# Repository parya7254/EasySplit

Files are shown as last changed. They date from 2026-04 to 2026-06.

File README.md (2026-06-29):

# EasySplit
A hot-swappable split keyboard with a traditional Layout! It will feature MX Switches, a nice!nano (clone) as the main MCU for both sides, and a battery so that it can be used on the go!

WhatsApp Image 2026-06-29 at 4 52 29 PM



# Why Did I Make This??
In school, I type A LOT. And typing on a school chromebook, is well, okay I guess, and I want to have a better typing experience when I type things, and well, I like making my own things and finding my own solutions. So I made this split keyboard. It's wireless, battery-powered, and best of all, **made by ME**. This keyboard will help me type my essays faster, work more efficiently, and also turn in my assignments **ON TIME**. *Ahhh*, yes, that's the feeling of making your own solutions and being proud of it.

# How Was it Made??

The PCB was designed using KiCAD and the case for it was designed in Fusion360. The pictures of the schematic and the PCB are below: 

This is the schematic which was designed in KiCad:





And this is the actual PCB which was also designed in KiCad:



# BOM
These will be the parts that I will use to build and assemble my split keyboard along with the links to get them:

| Name | Purpose | Quantity | Total Cost (USD) | Link | Distributor |
|---|---|---|---|---|---|
| PCB Mount Stabilizers Set | These will prevent wobble when pressing longer keys from the sides! | 1 | 9.99 | https://www.amazon.com/GLORIOUS-Stabilizer-Mechanical-Keyboards-Compatible/dp/B09MZKFLXP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 | Amazon |
| MX Hotswap Sockets (110pcs) | These will be the hotswap sockets for my split keyboard! They will allow for the switches to be removable and replaceable. | 1 | 7.99 | https://www.aliexpress.us/item/3256807045726008.html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 | AliExpress |
| 2.0mm JST Connector 2 Pin (5 Pairs) | This will be used to connect the battery to the nice!nano and using this, the battery can also be quickly removed without needing to be desoldered in case of problems or to power off the keyboard. | 1 | 1.76 | https://www.aliexpress.us/item/3256802377876396.html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 | AliExpress |
| nice!nano Clone | This will be the main MCU for both sides of my keyboard! It will basically read the key presses and send the respective key commands to the connected device. And it also has Bluetooth and a charging IC which means that the two halves of my split keyboard would be wirelessly connected and I can also directly charge my battery from it. | 2 | 5.52 | https://www.aliexpress.us/item/3256807196955871.html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 | AliExpress |
| 1N4148W SMD Small Signal Fast Switching Diodes (100pcs) | These will be the diodes that will be used in my switch matrix that will also help the microcontroller to read the pressed switches properly! | 1 | 1.38 | https://www.aliexpress.us/item/3256805388348871.html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 | AliExpress |
| ELUTENG Ice Blue Mechanical Keyboard Switches (100pcs) | These will be the switches that will be used in my keyboard! | 1 | 15.99 | https://www.amazon.com/gp/product/B0DHCLLH33/ref=ewc_pr_img_1?smid=A3GES9IA7UE877&th=1 | Amazon |
| 3.7V Battery (2pcs) | This will be the battery that will power both halves of my keyboard! | 1 | 8.35 | https://www.aliexpress.us/item/3256811793052939.html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 | AliExpress |
| Keycap Set | These will be the keycaps that I will use for my keyboard! | 1 | 14.39 | https://www.amazon.com/gp/product/B0BK3HK7SR/ref=ox_sc_act_image_1?smid=A157804XWFVRE0&th=1 | Amazon |
| PCB (Left and Right) MOQ: 5 | This will be my split keyboard's circuit board! | 5 | 34.00 | https://jlcpcb.com/ | JLCPCB |

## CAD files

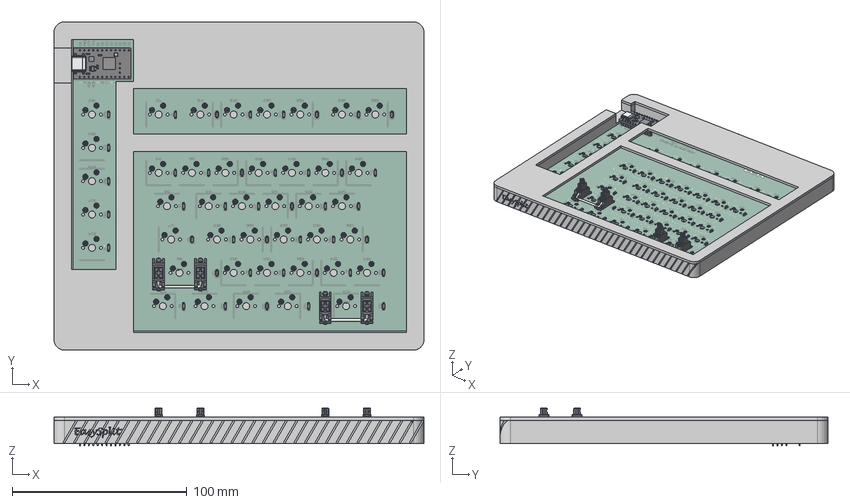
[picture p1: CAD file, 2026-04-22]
CAD/Left/EasySplit-Left-Assembled.stp
211.5 x 187.7 x 21.5 mm
D_SOD-123 x 42
Hotswap_MX x 42
PinHeader_1x12_P2.54mm_Vertical.step
User Library-TYPE-C-31-M-14.step
MICRO_603 resistor 102
micro_crystal 5x3
MICRO_led
micro_MIC5219
Stabilizer_MX_2.00u x 2
EasySplit - Left_copper
EasySplit - Left_pad
EasySplit - Left_via
EasySplit - Left_silkscreen
EasySplit - Left_silkscreen_1
EasySplit - Left_soldermask
EasySplit - Left_soldermask_1
EasySplit - Left_PCB

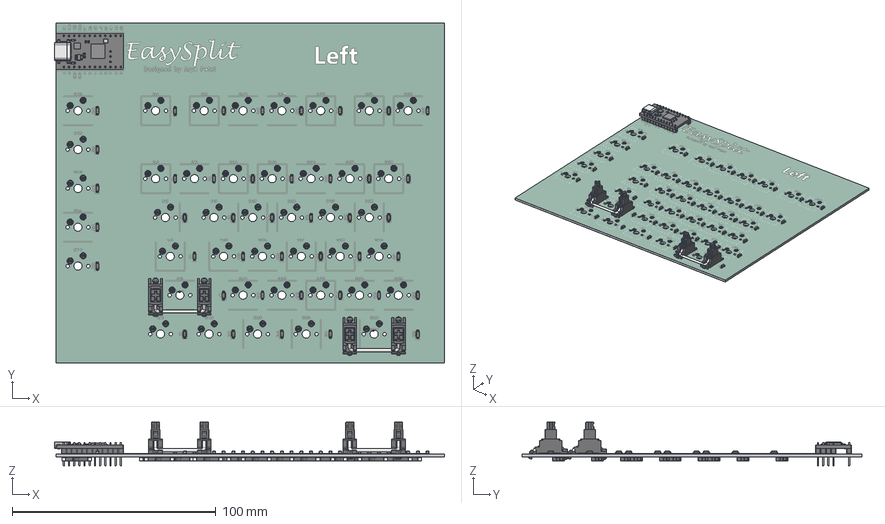
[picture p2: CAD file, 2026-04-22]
CAD/Left/EasySplit+-+Left.stp
191.3 x 166.7 x 21.5 mm
D_SOD-123 x 42
Hotswap_MX x 42
PinHeader_1x12_P2.54mm_Vertical.step
User Library-TYPE-C-31-M-14.step
MICRO_603 resistor 102
micro_crystal 5x3
MICRO_led
micro_MIC5219
Stabilizer_MX_2.00u x 2
EasySplit - Left_copper
EasySplit - Left_pad
EasySplit - Left_via
EasySplit - Left_silkscreen
EasySplit - Left_silkscreen_1
EasySplit - Left_soldermask
EasySplit - Left_soldermask_1
EasySplit - Left_PCB

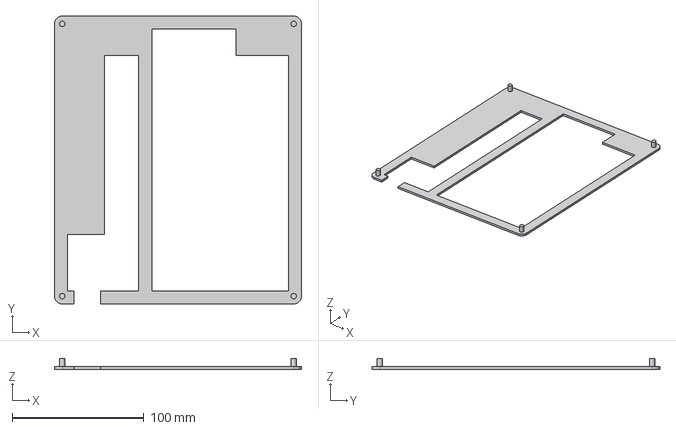
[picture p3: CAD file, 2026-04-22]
CAD/Right/EasySplit-Right-Top.stp
187.7 x 218.6 x 8.00 mm

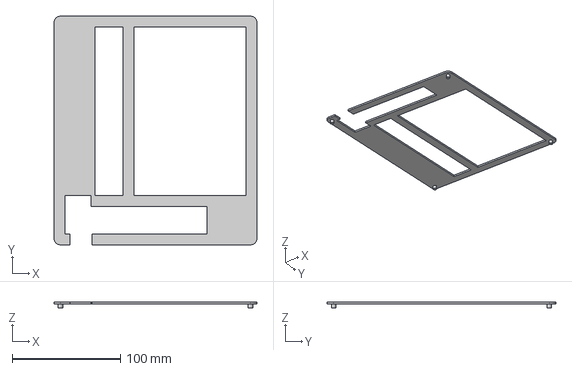
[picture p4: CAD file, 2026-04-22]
CAD/Left/EasySplit-Left-Top.stp
187.7 x 211.5 x 6.00 mm

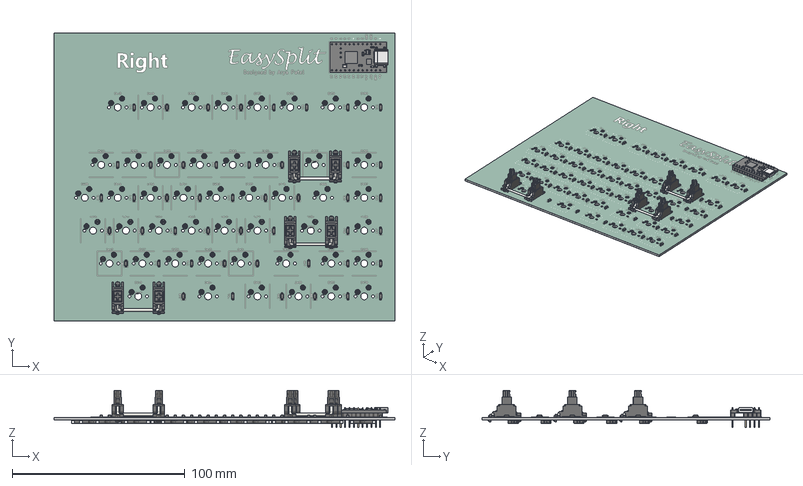
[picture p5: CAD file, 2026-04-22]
CAD/Right/EasySplit+-+Right.stp
197.6 x 166.7 x 21.5 mm
Hotswap_MX x 47
D_SOD-123 x 47
Stabilizer_MX_2.00u x 3
PinHeader_1x12_P2.54mm_Vertical.step
User Library-TYPE-C-31-M-14.step
MICRO_603 resistor 102
micro_crystal 5x3
MICRO_led
micro_MIC5219
EasySplit - Right_copper
EasySplit - Right_pad
EasySplit - Right_via
EasySplit - Right_silkscreen
EasySplit - Right_silkscreen_1
EasySplit - Right_soldermask
EasySplit - Right_soldermask_1
EasySplit - Right_PCB

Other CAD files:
CAD/EasySplit-Assembled-Full.f3z
CAD/Left/EasySplit+-+Left.f3d
CAD/Left/EasySplit-Left-Assembled.f3z
CAD/Left/EasySplit-Left-Top.f3d
CAD/Left/EasySplit-Left.f3d
CAD/Right/EasySplit+-+Right.f3d
CAD/Right/EasySplit-Right-Assembled.f3z
CAD/Right/EasySplit-Right-Top.f3d
CAD/Right/EasySplit-Right.f3d
CAD/Right/EasySplit-Right.stp

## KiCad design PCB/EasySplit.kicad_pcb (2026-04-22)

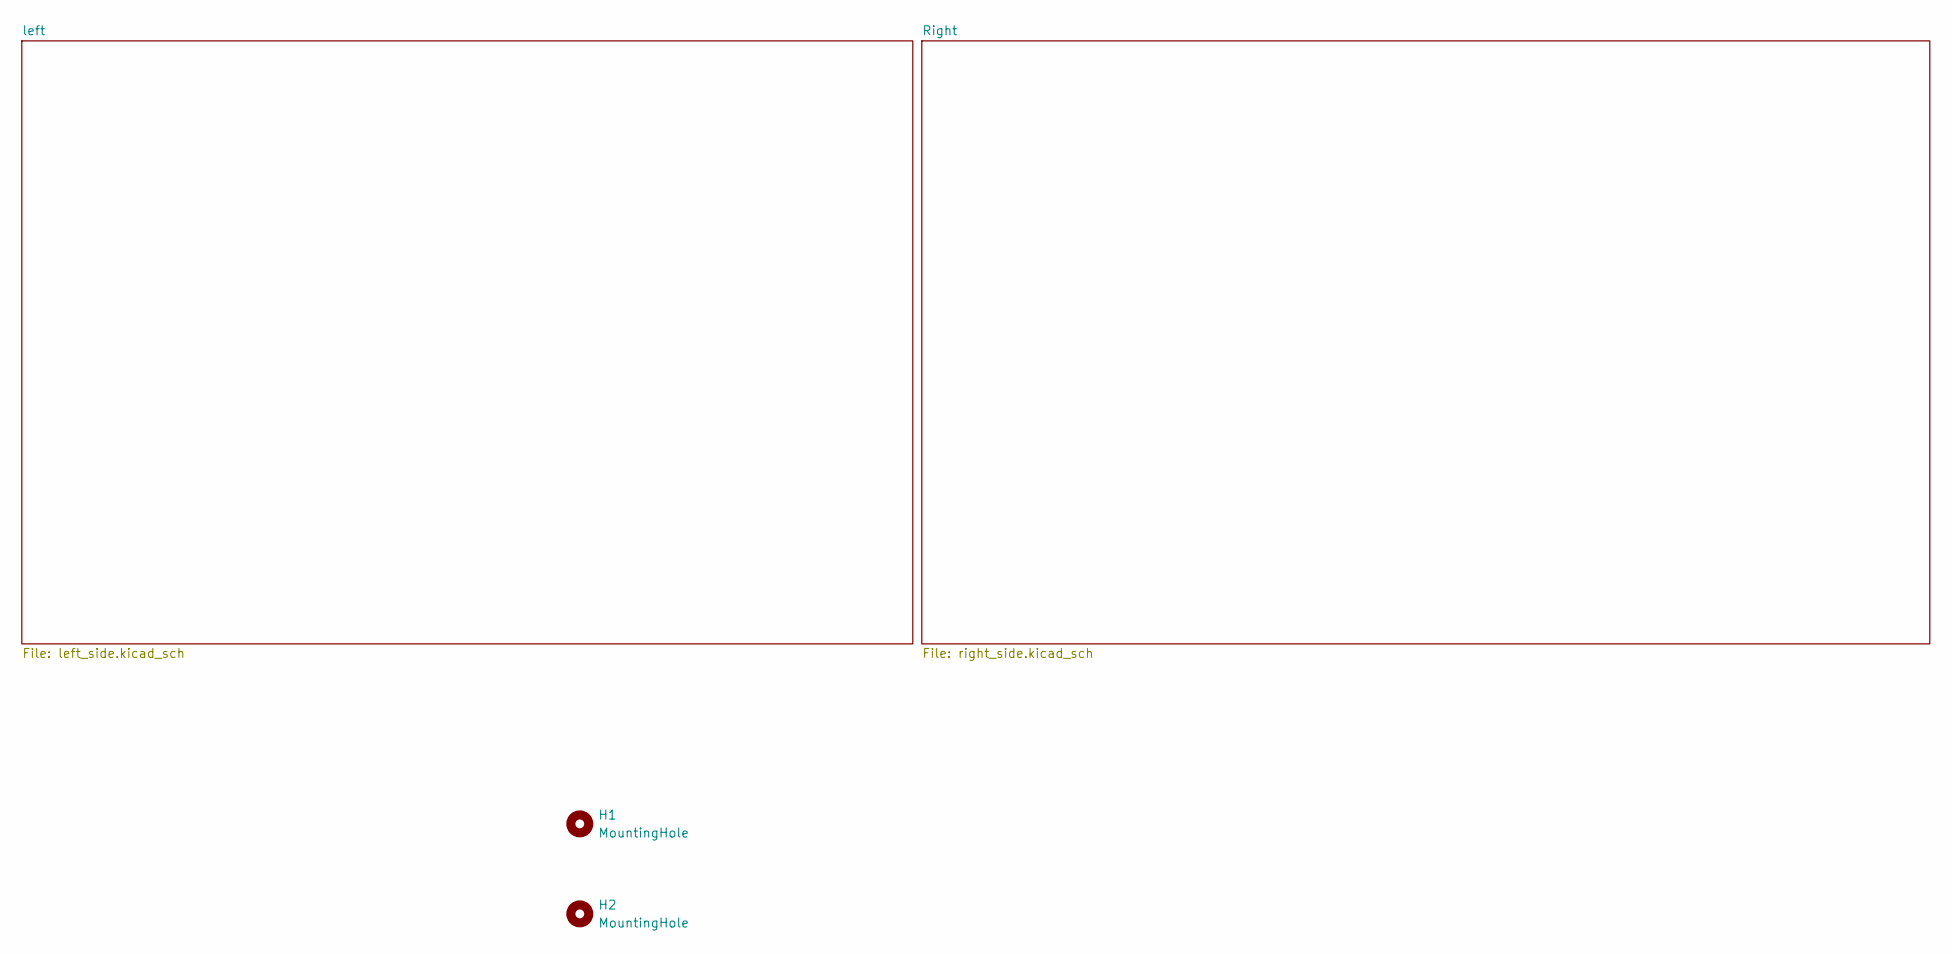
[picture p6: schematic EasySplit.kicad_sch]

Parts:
H1, H2: MountingHole; mouse-bite-5mm-slot

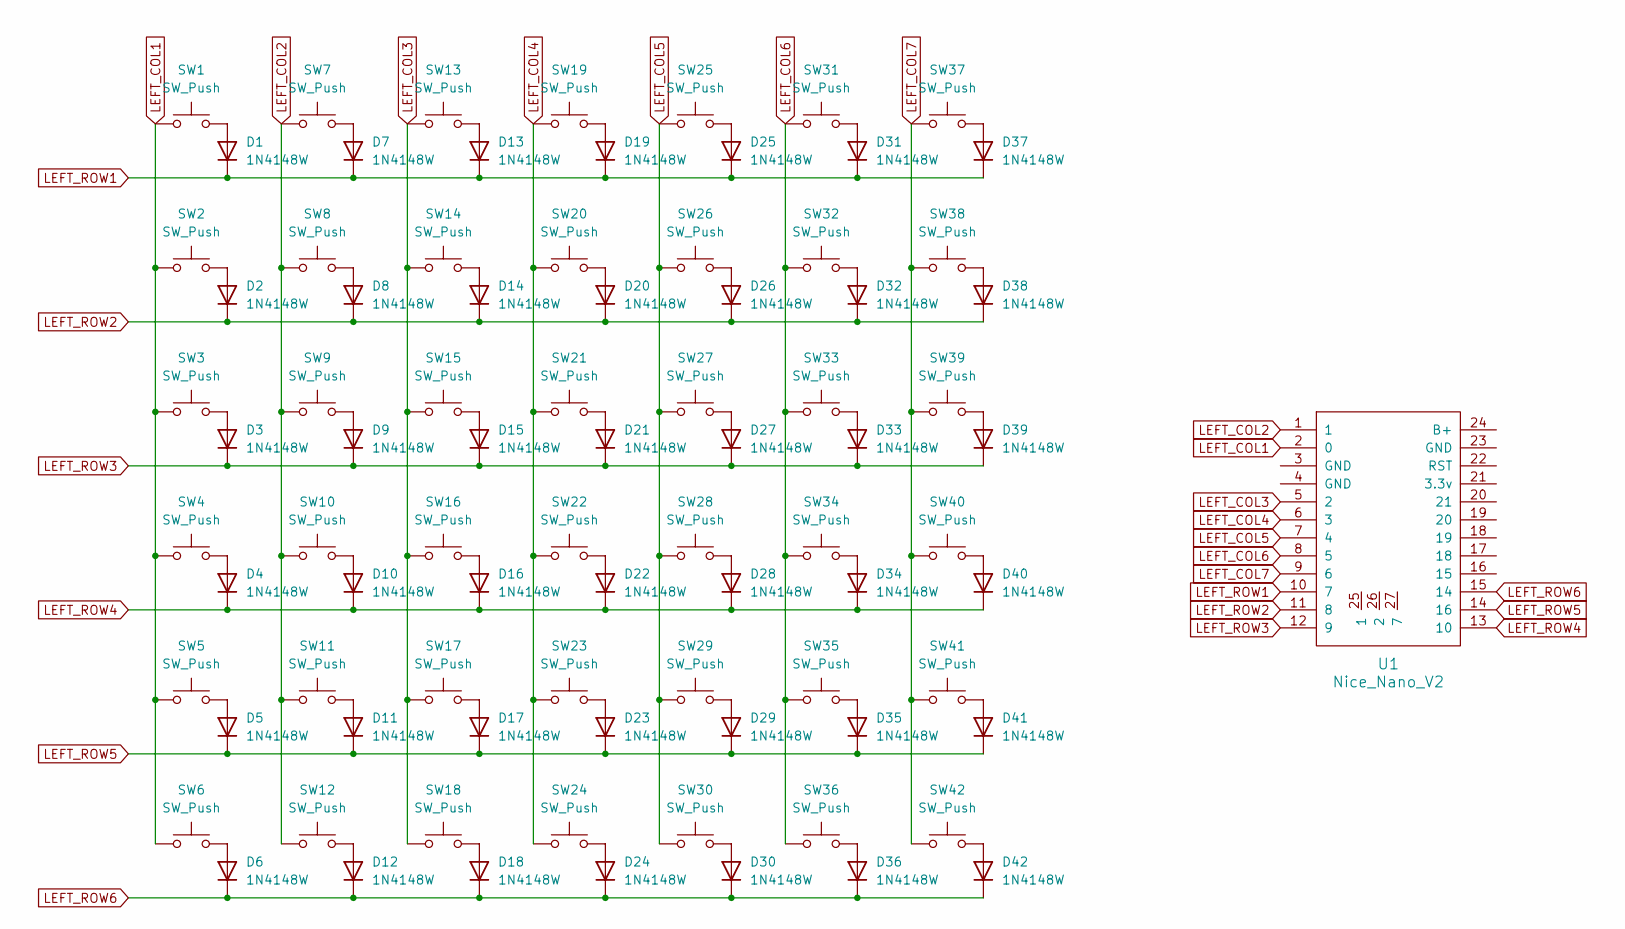
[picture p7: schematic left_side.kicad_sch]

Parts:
D1, D2, D3, D4, D5, D6, D7, D8, D9, D10, D11, D12, D13, D14, D15, D16, D17, D18, D19, D20, D21, D22, D23, D24, D25, D26, D27, D28, D29, D30, D31, D32, D33, D34, D35, D36, D37, D38, D39, D40, D41, D42: 1N4148W; D_SOD-123
SW1, SW2, SW7, SW8, SW9, SW10, SW11, SW13, SW14, SW15, SW16, SW17, SW19, SW20, SW21, SW22, SW23, SW25, SW26, SW27, SW28, SW29, SW31, SW32, SW33, SW34, SW35, SW36, SW37, SW38, SW39, SW40, SW41, SW42: SW_Push; Hotswap_MX_1.00u
SW3: SW_Push; Hotswap_MX_1.50u
SW4: SW_Push; Hotswap_MX_1.75u
SW5, SW30: SW_Push; Hotswap_MX_2.25u
SW6, SW12, SW18, SW24: SW_Push; Hotswap_MX_1.25u
U1: Nice_Nano_V2

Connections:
LEFT_COL1: SW1.1, SW2.1, SW3.1, SW4.1, SW5.1, SW6.1, U1.2 (0)
LEFT_COL2: SW7.1, SW8.1, SW9.1, SW10.1, SW11.1, SW12.1, U1.1
LEFT_COL3: SW13.1, SW14.1, SW15.1, SW16.1, SW17.1, SW18.1, U1.5 (2)
LEFT_COL4: SW19.1, SW20.1, SW21.1, SW22.1, SW23.1, SW24.1, U1.6 (3)
LEFT_COL5: SW25.1, SW26.1, SW27.1, SW28.1, SW29.1, SW30.1, U1.7 (4)
LEFT_COL6: SW31.1, SW32.1, SW33.1, SW34.1, SW35.1, SW36.1, U1.8 (5)
LEFT_COL7: SW37.1, SW38.1, SW39.1, SW40.1, SW41.1, SW42.1, U1.9 (6)
LEFT_ROW1: D1.1 (K), D7.1 (K), D13.1 (K), D19.1 (K), D25.1 (K), D31.1 (K), D37.1 (K), U1.10 (7)
LEFT_ROW2: D2.1 (K), D8.1 (K), D14.1 (K), D20.1 (K), D26.1 (K), D32.1 (K), D38.1 (K), U1.11 (8)
LEFT_ROW3: D3.1 (K), D9.1 (K), D15.1 (K), D21.1 (K), D27.1 (K), D33.1 (K), D39.1 (K), U1.12 (9)
LEFT_ROW4: D4.1 (K), D10.1 (K), D16.1 (K), D22.1 (K), D28.1 (K), D34.1 (K), D40.1 (K), U1.13 (10)
LEFT_ROW5: D5.1 (K), D11.1 (K), D17.1 (K), D23.1 (K), D29.1 (K), D35.1 (K), D41.1 (K), U1.14 (16)
LEFT_ROW6: D6.1 (K), D12.1 (K), D18.1 (K), D24.1 (K), D30.1 (K), D36.1 (K), D42.1 (K), U1.15 (14)
unnamed: D1.2 (A), SW1.2
unnamed: D2.2 (A), SW2.2
unnamed: D3.2 (A), SW3.2
unnamed: D4.2 (A), SW4.2
unnamed: D5.2 (A), SW5.2
unnamed: D6.2 (A), SW6.2
unnamed: D7.2 (A), SW7.2
unnamed: D8.2 (A), SW8.2
unnamed: D9.2 (A), SW9.2
unnamed: D10.2 (A), SW10.2
unnamed: D11.2 (A), SW11.2
unnamed: D12.2 (A), SW12.2
unnamed: D13.2 (A), SW13.2
unnamed: D14.2 (A), SW14.2
unnamed: D15.2 (A), SW15.2
unnamed: D16.2 (A), SW16.2
unnamed: D17.2 (A), SW17.2
unnamed: D18.2 (A), SW18.2
unnamed: D19.2 (A), SW19.2
unnamed: D20.2 (A), SW20.2
unnamed: D21.2 (A), SW21.2
unnamed: D22.2 (A), SW22.2
unnamed: D23.2 (A), SW23.2
unnamed: D24.2 (A), SW24.2
unnamed: D25.2 (A), SW25.2
unnamed: D26.2 (A), SW26.2
unnamed: D27.2 (A), SW27.2
unnamed: D28.2 (A), SW28.2
unnamed: D29.2 (A), SW29.2
unnamed: D30.2 (A), SW30.2
unnamed: D31.2 (A), SW31.2
unnamed: D32.2 (A), SW32.2
unnamed: D33.2 (A), SW33.2
unnamed: D34.2 (A), SW34.2
unnamed: D35.2 (A), SW35.2
unnamed: D36.2 (A), SW36.2
unnamed: D37.2 (A), SW37.2
unnamed: D38.2 (A), SW38.2
unnamed: D39.2 (A), SW39.2
unnamed: D40.2 (A), SW40.2
unnamed: D41.2 (A), SW41.2
unnamed: D42.2 (A), SW42.2

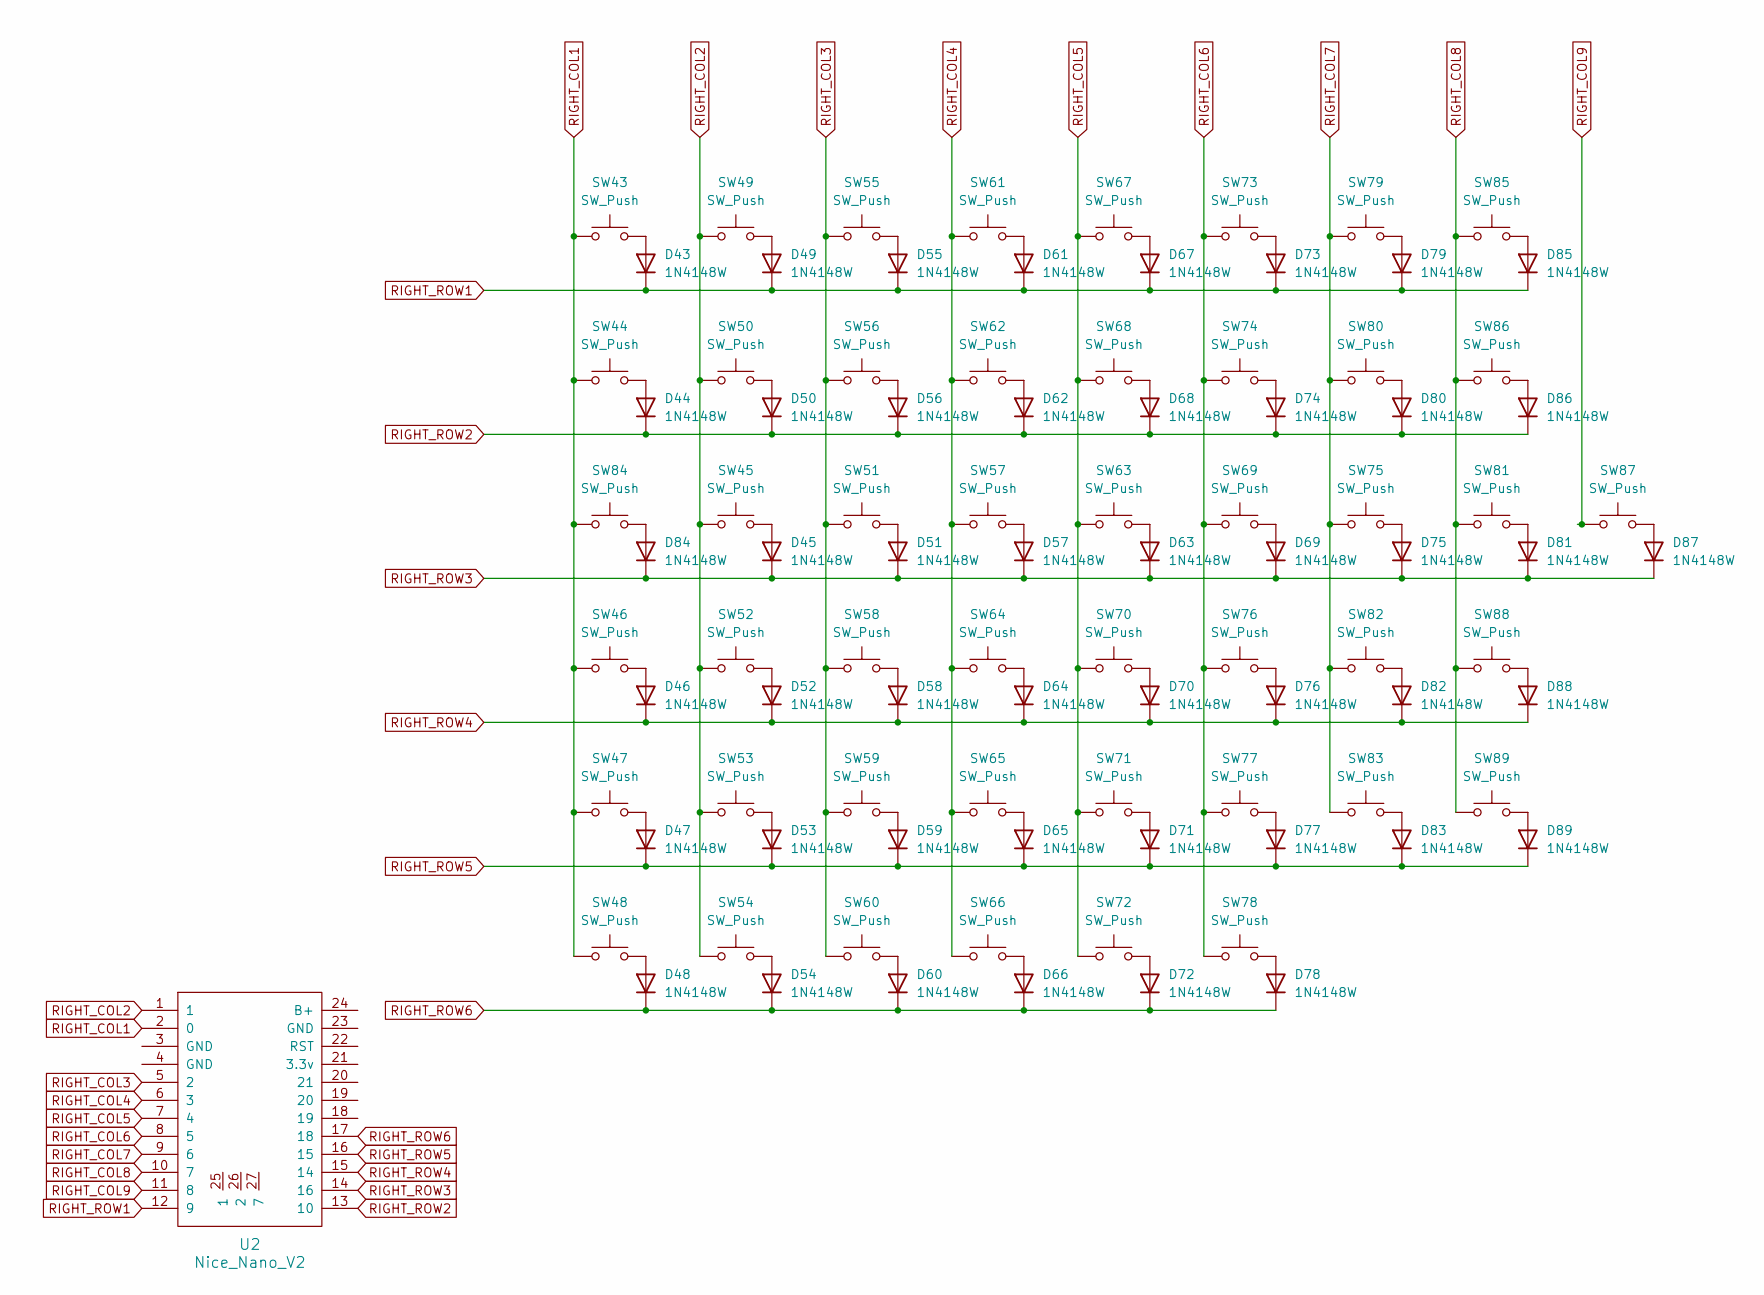
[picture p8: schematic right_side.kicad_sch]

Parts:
D43, D44, D45, D46, D47, D48, D49, D50, D51, D52, D53, D54, D55, D56, D57, D58, D59, D60, D61, D62, D63, D64, D65, D66, D67, D68, D69, D70, D71, D72, D73, D74, D75, D76, D77, D78, D79, D80, D81, D82, D83, D84, D85, D86, D87, D88, D89: 1N4148W; D_SOD-123
SW43, SW44, SW45, SW46, SW47, SW49, SW50, SW51, SW52, SW53, SW55, SW56, SW57, SW58, SW59, SW61, SW62, SW63, SW64, SW65, SW66, SW67, SW68, SW69, SW70, SW71, SW72, SW73, SW74, SW75, SW76, SW78, SW79, SW83, SW84, SW85, SW86, SW87, SW88, SW89: SW_Push; Hotswap_MX_1.00u
SW48: SW_Push; Hotswap_MX_2.75u
SW54, SW60, SW81: SW_Push; Hotswap_MX_1.50u
SW77: SW_Push; Hotswap_MX_1.75u
SW80: SW_Push; Hotswap_MX_2.00u
SW82: SW_Push; Hotswap_MX_2.25u
U2: Nice_Nano_V2

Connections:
unnamed: D43.2 (A), SW43.2
unnamed: D44.2 (A), SW44.2
unnamed: D45.2 (A), SW45.2
unnamed: D46.2 (A), SW46.2
unnamed: D47.2 (A), SW47.2
unnamed: D48.2 (A), SW48.2
unnamed: D49.2 (A), SW49.2
unnamed: D50.2 (A), SW50.2
unnamed: D51.2 (A), SW51.2
unnamed: D52.2 (A), SW52.2
unnamed: D53.2 (A), SW53.2
unnamed: D54.2 (A), SW54.2
unnamed: D55.2 (A), SW55.2
unnamed: D56.2 (A), SW56.2
unnamed: D57.2 (A), SW57.2
unnamed: D58.2 (A), SW58.2
unnamed: D59.2 (A), SW59.2
unnamed: D60.2 (A), SW60.2
unnamed: D61.2 (A), SW61.2
unnamed: D62.2 (A), SW62.2
unnamed: D63.2 (A), SW63.2
unnamed: D64.2 (A), SW64.2
unnamed: D65.2 (A), SW65.2
unnamed: D66.2 (A), SW66.2
unnamed: D67.2 (A), SW67.2
unnamed: D68.2 (A), SW68.2
unnamed: D69.2 (A), SW69.2
unnamed: D70.2 (A), SW70.2
unnamed: D71.2 (A), SW71.2
unnamed: D72.2 (A), SW72.2
unnamed: D73.2 (A), SW73.2
unnamed: D74.2 (A), SW74.2
unnamed: D75.2 (A), SW75.2
unnamed: D76.2 (A), SW76.2
unnamed: D77.2 (A), SW77.2
unnamed: D78.2 (A), SW78.2
unnamed: D79.2 (A), SW79.2
unnamed: D80.2 (A), SW80.2
unnamed: D81.2 (A), SW81.2
unnamed: D82.2 (A), SW82.2
unnamed: D83.2 (A), SW83.2
unnamed: D84.2 (A), SW84.2
unnamed: D85.2 (A), SW85.2
unnamed: D86.2 (A), SW86.2
unnamed: D87.2 (A), SW87.2
unnamed: D88.2 (A), SW88.2
unnamed: D89.2 (A), SW89.2
RIGHT_COL1: SW43.1, SW44.1, SW46.1, SW47.1, SW48.1, SW84.1, U2.2 (0)
RIGHT_COL2: SW45.1, SW49.1, SW50.1, SW52.1, SW53.1, SW54.1, U2.1
RIGHT_COL3: SW51.1, SW55.1, SW56.1, SW58.1, SW59.1, SW60.1, U2.5 (2)
RIGHT_COL4: SW57.1, SW61.1, SW62.1, SW64.1, SW65.1, SW66.1, U2.6 (3)
RIGHT_COL5: SW63.1, SW67.1, SW68.1, SW70.1, SW71.1, SW72.1, U2.7 (4)
RIGHT_COL6: SW69.1, SW73.1, SW74.1, SW76.1, SW77.1, SW78.1, U2.8 (5)
RIGHT_COL7: SW75.1, SW79.1, SW80.1, SW82.1, SW83.1, U2.9 (6)
RIGHT_COL8: SW81.1, SW85.1, SW86.1, SW88.1, SW89.1, U2.10 (7)
RIGHT_COL9: SW87.1, U2.11 (8)
RIGHT_ROW1: D43.1 (K), D49.1 (K), D55.1 (K), D61.1 (K), D67.1 (K), D73.1 (K), D79.1 (K), D85.1 (K), U2.12 (9)
RIGHT_ROW2: D44.1 (K), D50.1 (K), D56.1 (K), D62.1 (K), D68.1 (K), D74.1 (K), D80.1 (K), D86.1 (K), U2.13 (10)
RIGHT_ROW3: D45.1 (K), D51.1 (K), D57.1 (K), D63.1 (K), D69.1 (K), D75.1 (K), D81.1 (K), D84.1 (K), D87.1 (K), U2.14 (16)
RIGHT_ROW4: D46.1 (K), D52.1 (K), D58.1 (K), D64.1 (K), D70.1 (K), D76.1 (K), D82.1 (K), D88.1 (K), U2.15 (14)
RIGHT_ROW5: D47.1 (K), D53.1 (K), D59.1 (K), D65.1 (K), D71.1 (K), D77.1 (K), D83.1 (K), D89.1 (K), U2.16 (15)
RIGHT_ROW6: D48.1 (K), D54.1 (K), D60.1 (K), D66.1 (K), D72.1 (K), D78.1 (K), U2.17 (18)

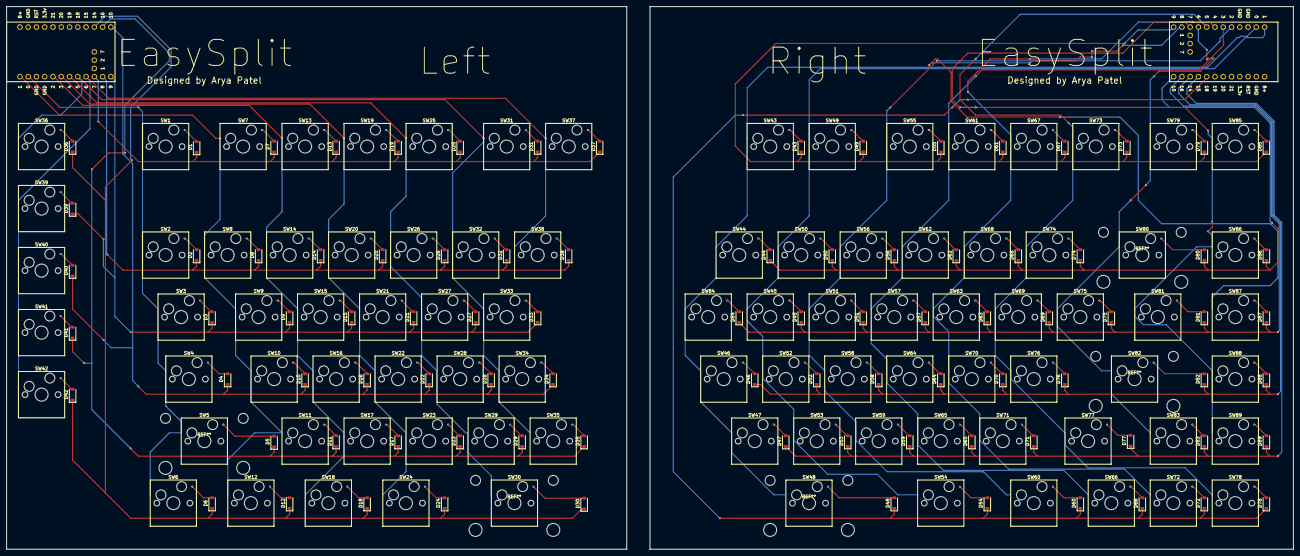
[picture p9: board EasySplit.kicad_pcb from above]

Board: 2 copper layers, 395.3 x 166.7 mm, 180 parts (0 on the bottom side), 117 nets.

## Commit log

2026-04-11 Update switch type from low-profile to MX Switches
2026-04-22 Uploaded all files!!
    [EasySplit+-+Left.f3d, EasySplit+-+Left.stp, EasySplit+-+Right.f3d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]
2026-04-22 Revise README for EasySplit keyboard project
    Updated the README to enhance clarity and detail about the EasySplit keyboard project, including the BOM and images.
2026-04-22 Uploaded PCB Files!!
    [EasySplit - Left.kicad_pcb, EasySplit - Right.kicad_pcb, EasySplit.kicad_pcb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]
2026-04-23 Update README with new schematic and PCB images
    Added additional images of the schematic and PCB designed in KiCad.
2026-04-24 Organized PCB Files!!
    [EasySplit - Left.kicad_pcb, EasySplit - Right.kicad_pcb, left_side.kicad_sch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]
